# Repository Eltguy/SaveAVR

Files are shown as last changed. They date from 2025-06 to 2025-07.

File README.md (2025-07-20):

# SaveAVR

### HV-Programmiersystem für AVR-MCUs

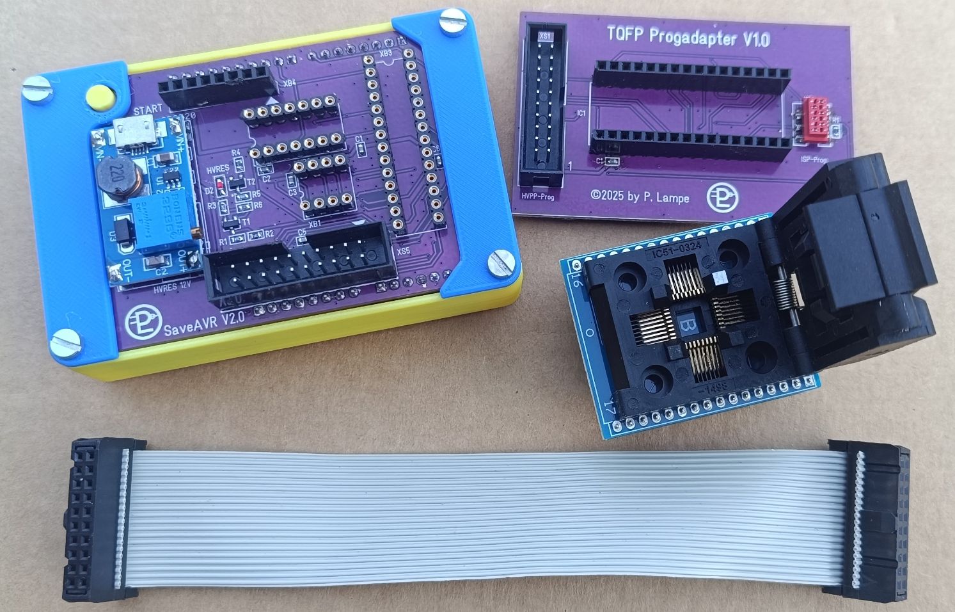
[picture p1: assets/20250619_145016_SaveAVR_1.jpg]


Ich hatte immer wieder Probleme mit AVR-Controllern, beim Setzen der Fuses. Insbesondere beim Entfernen des Vorteilers oder bei der Festlegung der Taktquelle, gab es mitunter Probleme beim Schreiben. Das Resultat war ein Controller, den man über den gängigen ISP-Modus nicht mehr programmieren kann. Laut Datenblatt gibt es dafür einen Ausweg - die Hochspannungsprogrammierung. Hochspannung bedeutet hier 12V. Legt man die an RESET an, ermöglicht das eine spezielle Programmierweise, unabhängig von der aktuellen Fuses- und Lockbitkonfiguration. Je nach Controllertyp kann das parallel (HVPP) oder seriell (HVSP) erfolgen.

Bei meinen Recherchen bin ich auf bereits vorhandene Lösungen gestoßen. Insbesonder die Variante, die im Artikel [RescueAVR](https://github.com/felias-fogg/RescueAVR) beschrieben wurde, fand ich sehr gut. Hier wird ein passendes HV-Programmer-Board beschrieben, das auf einen Arduino Uno aufgesetzt wird. Dieser enthält eine entsprechende Steuersoftware, mit der man über ein Terminalprogramm, die betroffenen MCUs wieder in deren Ursprungszustand zurückversetzen kann. Das Board funktioniert prima und ich möchte an dieser Stelle "felias-fogg" meinen Dank aussprechen.

### Systembeschreibung

Ausgehend von diesem Board, wurde eine eigene Variante für einen HV-Programmer entwickelt. Die Controller im DIL-Gehäuse werden von mir kaum genutzt. Mir war es deshalb wichtig, dass auch Controller mit TQFP32-Gehäuse unterstützt werden. Deshalb wurde von mir die 20pol. Buchsenleiste durch einen Wannenstecker ersetzt.  TQFP-Adapter gibt es preiswert über Aliexpress. Dafür habe ich einen separaten Programmieradapter designed. Dieser ist ebenfalls mit einem Wannenstecke ausgestattet. Die Verbindung erfolgt mit einem Flachbandkabel über Pfostenbuchsen. Zusätzlich hat der Adapter noch eine 6pol. Micromatch-SMD-Buchse. Darüber ist zusätzlich auch die ISP-Programmierung möglich. 

Des Weiteren habe ich als 12V-Quelle das allseits verfügbare Booster-Modul mit dem MT3608 verwendet. Letztendlich wurde das Routing noch optimiert und alles konsequent auf SMD-Bauelemente umgestellt.

Zur besseren Handhabbarkeit wurden alle Komponenten in ein Gehäuse aus 3D-Druckteilen eingebaut. Hierbei wurde auch an eine RESET-Knopf-Verlängerung für den Arduino Uno  gedacht, um das Terminalprogramm gegebenenfalls neu zu starten. Der Zusammenbau ist recht einfach und kann den Fotos und CAD-Ansichten entnommen werden. Unter der TQFP-Platine werden lediglich noch 4 selbstklebende Füße angebracht. 

Die Bauunterlagen des Projekts, inklusive die Gerber-Daten für die Leiterplatten, liegen im Ordner DOKUMENTE und sind auch auf meiner Webseite [Eltguy.de](https://eltguy.de/selbstbauprojekte-elektronik-technik-hobbytechnologien/flash-tools-programmiertool-esp-avr-adapter). Sie sind unter Beachtung der Lizenzbedingungen zur persönlichen Verwendung freigegeben. Bezüglich der Firmware für den Arduino Uno, verweise ich auf den Beitrag bei [RescueAVR](https://github.com/felias-fogg/RescueAVR). Ist die <em>RescuAVR.ino</em> einmal auf den Uno geflasht, kann man sich mit einem Terminalprogramm (z.B. Hterm), über den virtuellen COM-Port und einer Baudrate von 19200, mit dem Gerät verbinden. Dann ist einfach dem Programm zu folgen.

Bei Betrieb bitte beachten, dass die Controller <strong>nur bei abgeschalteter Betriebsspannung (USB-Stecker gezogen) gewechselt werden dürfen</strong> 👀️!

### Lizenzierung

Die hier beschriebenen Hardwarekomponenten dürfen ausschließlich für private Anwendungen gebaut und verwendet werden. Ich gestatte auch die Nutzung der bereitgestellten Entwicklungsunterlagen, die ich zum Download anbiete. Eine kommerzielle Nutzung schließe ich definitiv aus! Es ist nicht gestattet, Kennzeichnungen, die auf den geistigen Ursprung der Projekte hinweisen (Copyrights, Logos, Namen,…) aus Entwicklungsunterlagen der Anlage und Anlagenteilen zu entfernen. Nachbau und Nutzung erfolgen auf eigenes Risiko. Ich hafte nicht für Schäden, die durch die Nutzung der Software, der Anlage oder Anlagenkomponenten entstehen.

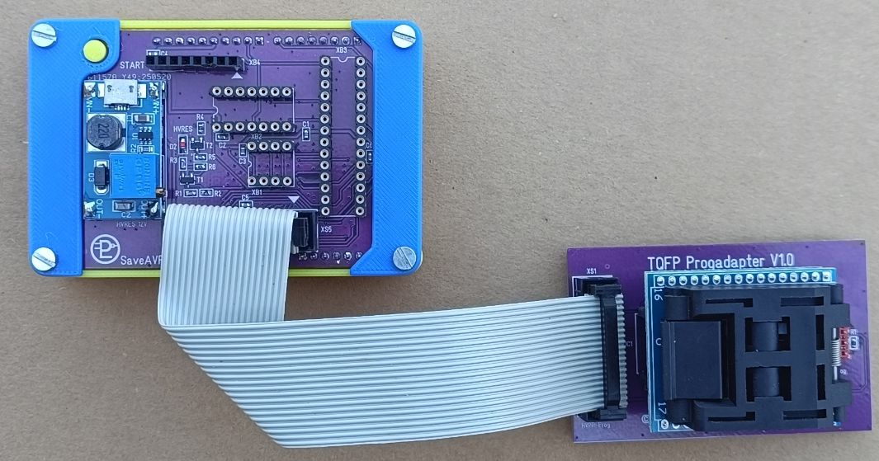
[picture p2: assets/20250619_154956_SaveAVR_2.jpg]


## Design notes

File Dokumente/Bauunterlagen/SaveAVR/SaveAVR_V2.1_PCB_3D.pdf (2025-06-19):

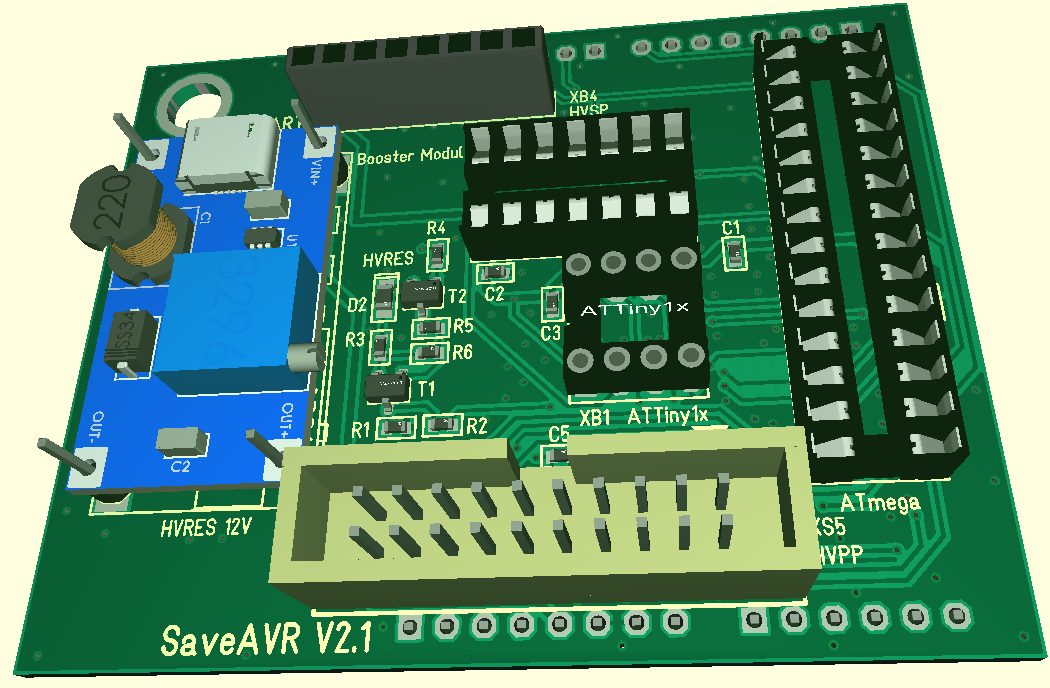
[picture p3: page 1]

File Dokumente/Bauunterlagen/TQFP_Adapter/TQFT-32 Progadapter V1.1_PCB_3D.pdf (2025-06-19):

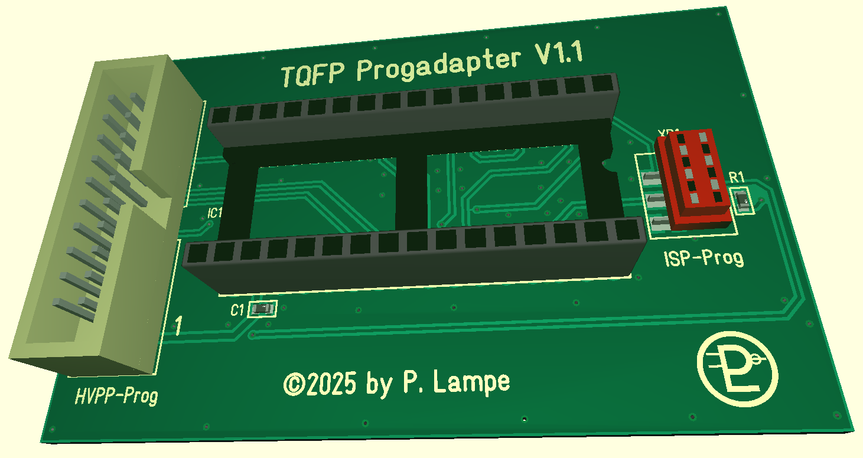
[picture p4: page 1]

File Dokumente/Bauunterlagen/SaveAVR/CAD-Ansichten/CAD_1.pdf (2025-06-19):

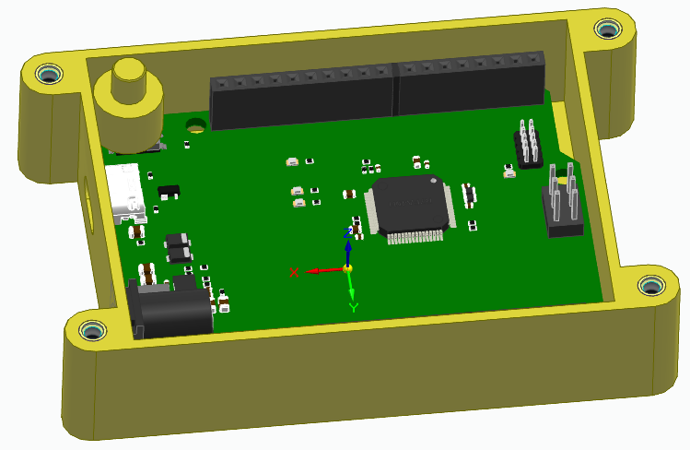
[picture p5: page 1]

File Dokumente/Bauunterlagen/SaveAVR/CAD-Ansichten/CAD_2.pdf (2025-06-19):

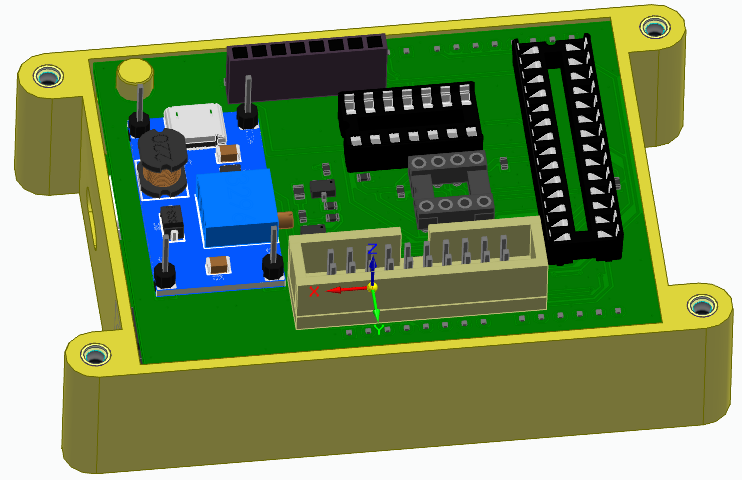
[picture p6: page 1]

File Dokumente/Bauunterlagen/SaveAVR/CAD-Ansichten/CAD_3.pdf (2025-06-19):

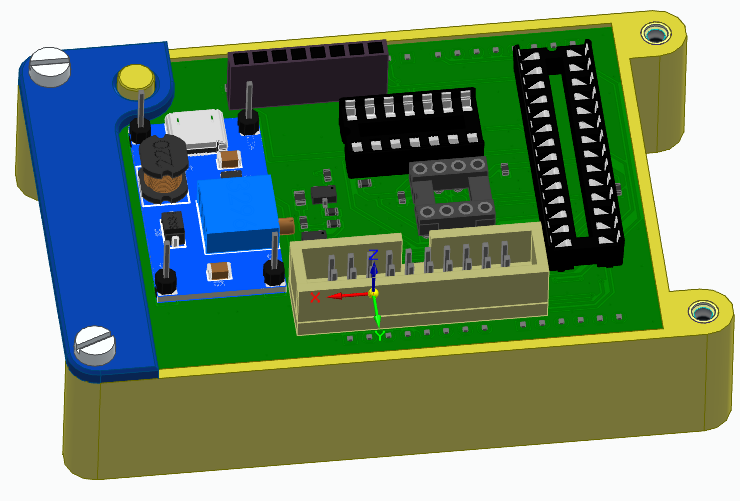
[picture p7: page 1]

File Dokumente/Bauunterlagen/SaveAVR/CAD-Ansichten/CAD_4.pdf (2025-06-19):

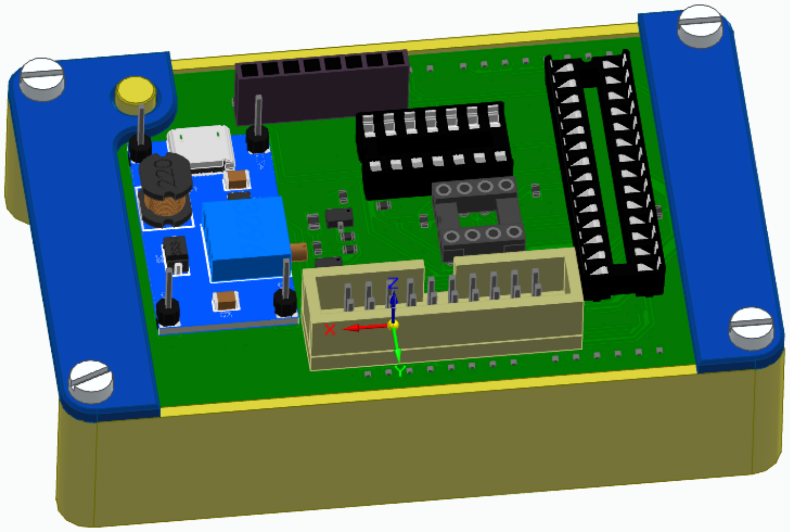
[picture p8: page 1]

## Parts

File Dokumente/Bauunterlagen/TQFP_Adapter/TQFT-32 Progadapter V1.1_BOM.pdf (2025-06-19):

## BOM

Datum 19.Juni.2025 12:32
Autor | Peter Lampe
Pos | Anzahl | Name | Wert | Gehäuse | Bemerkung
1 | 2 | C1, C2 | SMD-MLC 100n | 0603
2 | 2 | K2,K3 | 1X16_BUCHSE (TQFP-Socket) | 1X16_BUCHSE
3 | 1 | R1 | SMD-Widerstand 82k | 0603
4 | 1 | XB1 | Micromatch-SMD-Buchse 6pol. (ISP-Prog) | Micromatch 6pol
5 | 1 | XS1 | Wannenstecker 2x10pol (HVPP) | WANNENSTECKER-20-ST
6 | 4 | | selbstklebende Füße, unter PCB kleben | | Aliexpress (https://de.aliexpress.com/item/1005004068119765.html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)
7 | 1 | TQFP32-Adapter, in Pos.2 stecken

Aliexpress (https://de.aliexpress.com/item/1005007044669572.html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)

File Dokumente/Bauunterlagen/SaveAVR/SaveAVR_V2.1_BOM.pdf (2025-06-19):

### BOM

Datum | 19.Juni.2025 11:30
;Autor | Peter Lampe
Pos | Anzahl | Name | Wert | Gehäuse | Bemerkung
1 | 6 | C1...C6 | SMD-MLC 100nF | 0603
2 | 1 | R2 | SMD-Widerstand 100 | 0603
3 | 3 | R1, R3, R5 | SMD-Widerstand 1k | 0603
4 | 1 | R4 | SMD-Widerstand 4,7k | 0603
5 | 1 | R6 | SMD-Widerstand 10k | 0603
6 | | D2 | rt | 0805
7 | 1 | T1 | SMD-Transistor; pnp; BC857A | SOT23/3
8 | 1 | T2 | SMD-Transistor;npn; BC846A | SOT23/3
9 | 4 | KL1...KL4 | Stiftleiste 1x1pol | Stiftleiste_1x01_G_2,54
10 | 1 | M1 | Booster Modul MT3608 | MT3608_PCB | Aliexpress (https://de.aliexpress.com/item/1005007329944366.html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)
11 | 1 | XB1 | IC-Fassung 2x4 (ATTiny1x) | IC-SOCKET_DIL8 MACHINE PIN
12 | 1 | XB2 | IC-Fassung 2x8 (ATtinyX4) | IC-FASSUNG RM 7.62 - 14 POLIG
13 | 1 | XB3 | IC-Fassung 2x14 (ATmegax8) | IC-FASSUNG RM 7.62 - 28 POLIG
14 | 1 | XB4 | Buchsenleiste 1x8pol. (HVSP) | 1X08_BUCHSE
15 | 2 | XS1, XS3 | Stiftleiste 1x8pol | Stiftleiste_1x08_G_2,54
16 | 1 | XS2 | Stiftleiste 1x10pol | Stiftleiste_1x10_G_2,54
17 | 1 | XS4 | Stiftleiste 1x6pol | Stiftleiste_1x06_G_2,54
18 | 1 | XS5 | Wannenstecker 2x10pol (HVPP) | WANNENSTECKER-20-ST

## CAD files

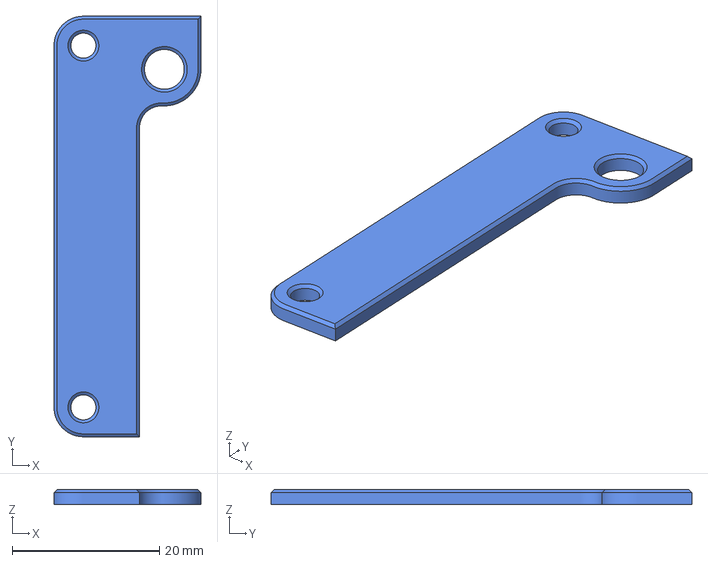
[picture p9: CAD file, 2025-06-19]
Dokumente/3D-Teile/Abdeckklammer Knopf.3mf
20.0 x 57.2 x 2.00 mm

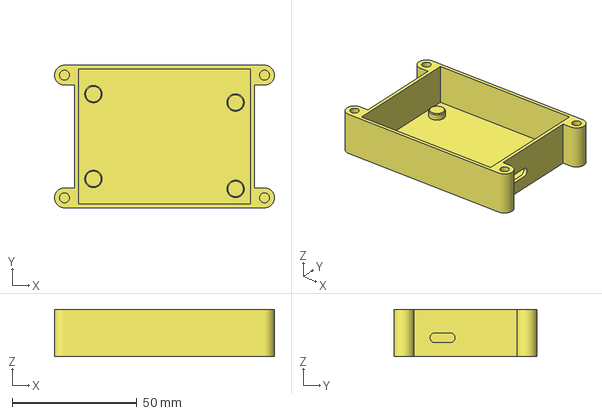
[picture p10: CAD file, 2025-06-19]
Dokumente/3D-Teile/saveAVR_Unterschale.3mf
88.2 x 57.2 x 19.0 mm

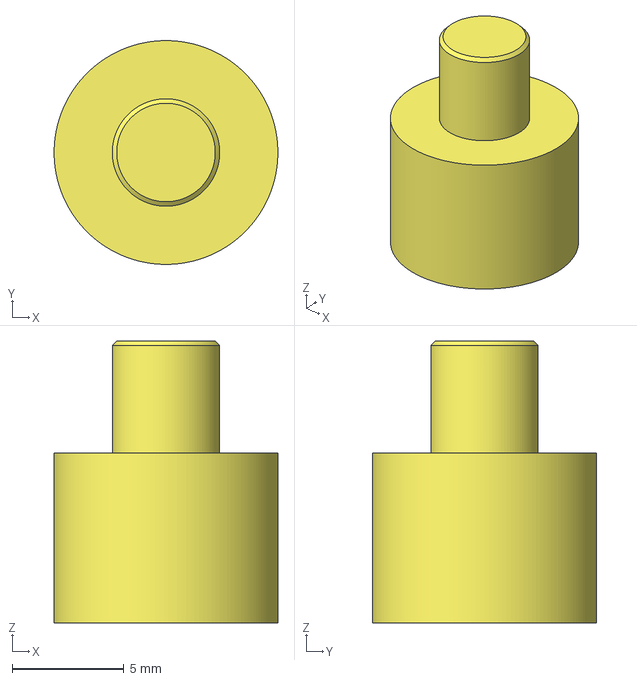
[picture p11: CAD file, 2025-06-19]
Dokumente/3D-Teile/Druckknopf 2.3mf
10.0 x 10.00 x 12.6 mm

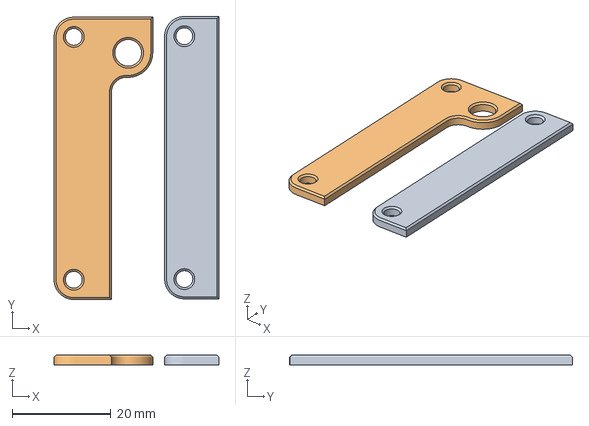
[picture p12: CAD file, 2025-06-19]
Dokumente/3D-Teile/Abdeckklammer.3mf
33.4 x 57.3 x 2.00 mm
Abdeckramen einfach
Abdeckramen Knopf

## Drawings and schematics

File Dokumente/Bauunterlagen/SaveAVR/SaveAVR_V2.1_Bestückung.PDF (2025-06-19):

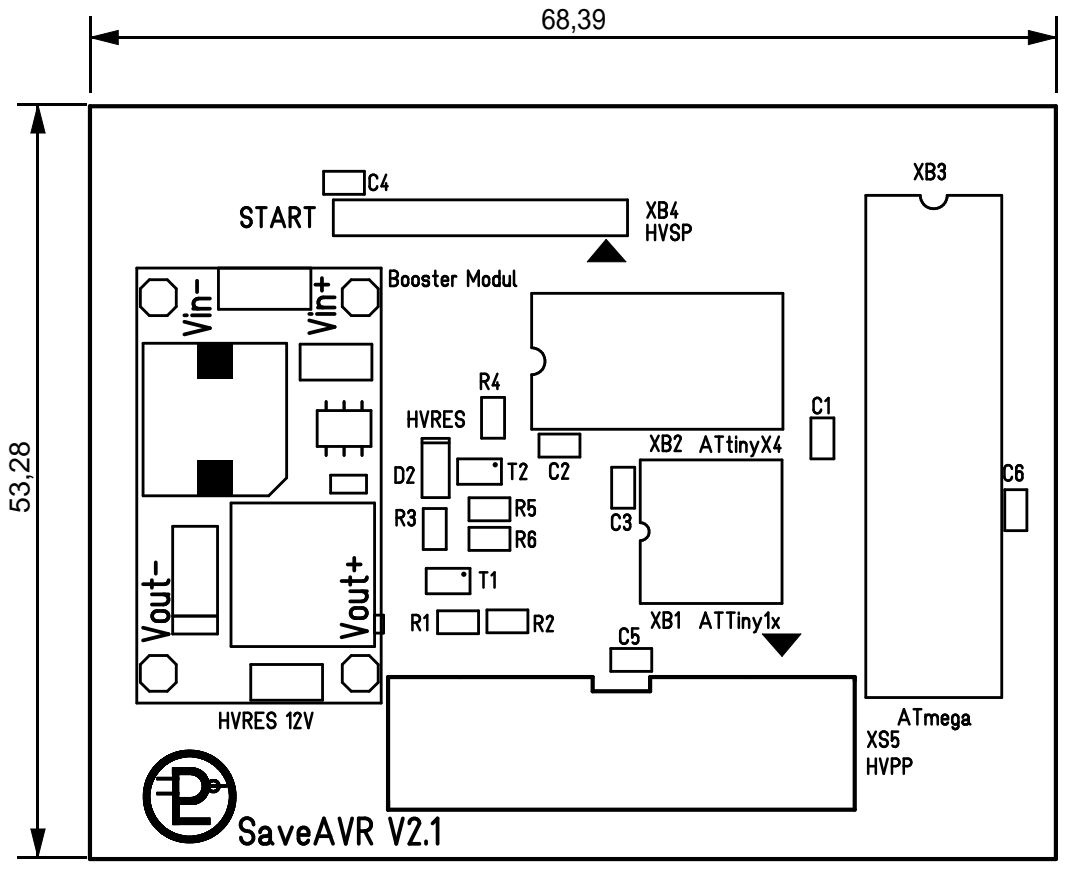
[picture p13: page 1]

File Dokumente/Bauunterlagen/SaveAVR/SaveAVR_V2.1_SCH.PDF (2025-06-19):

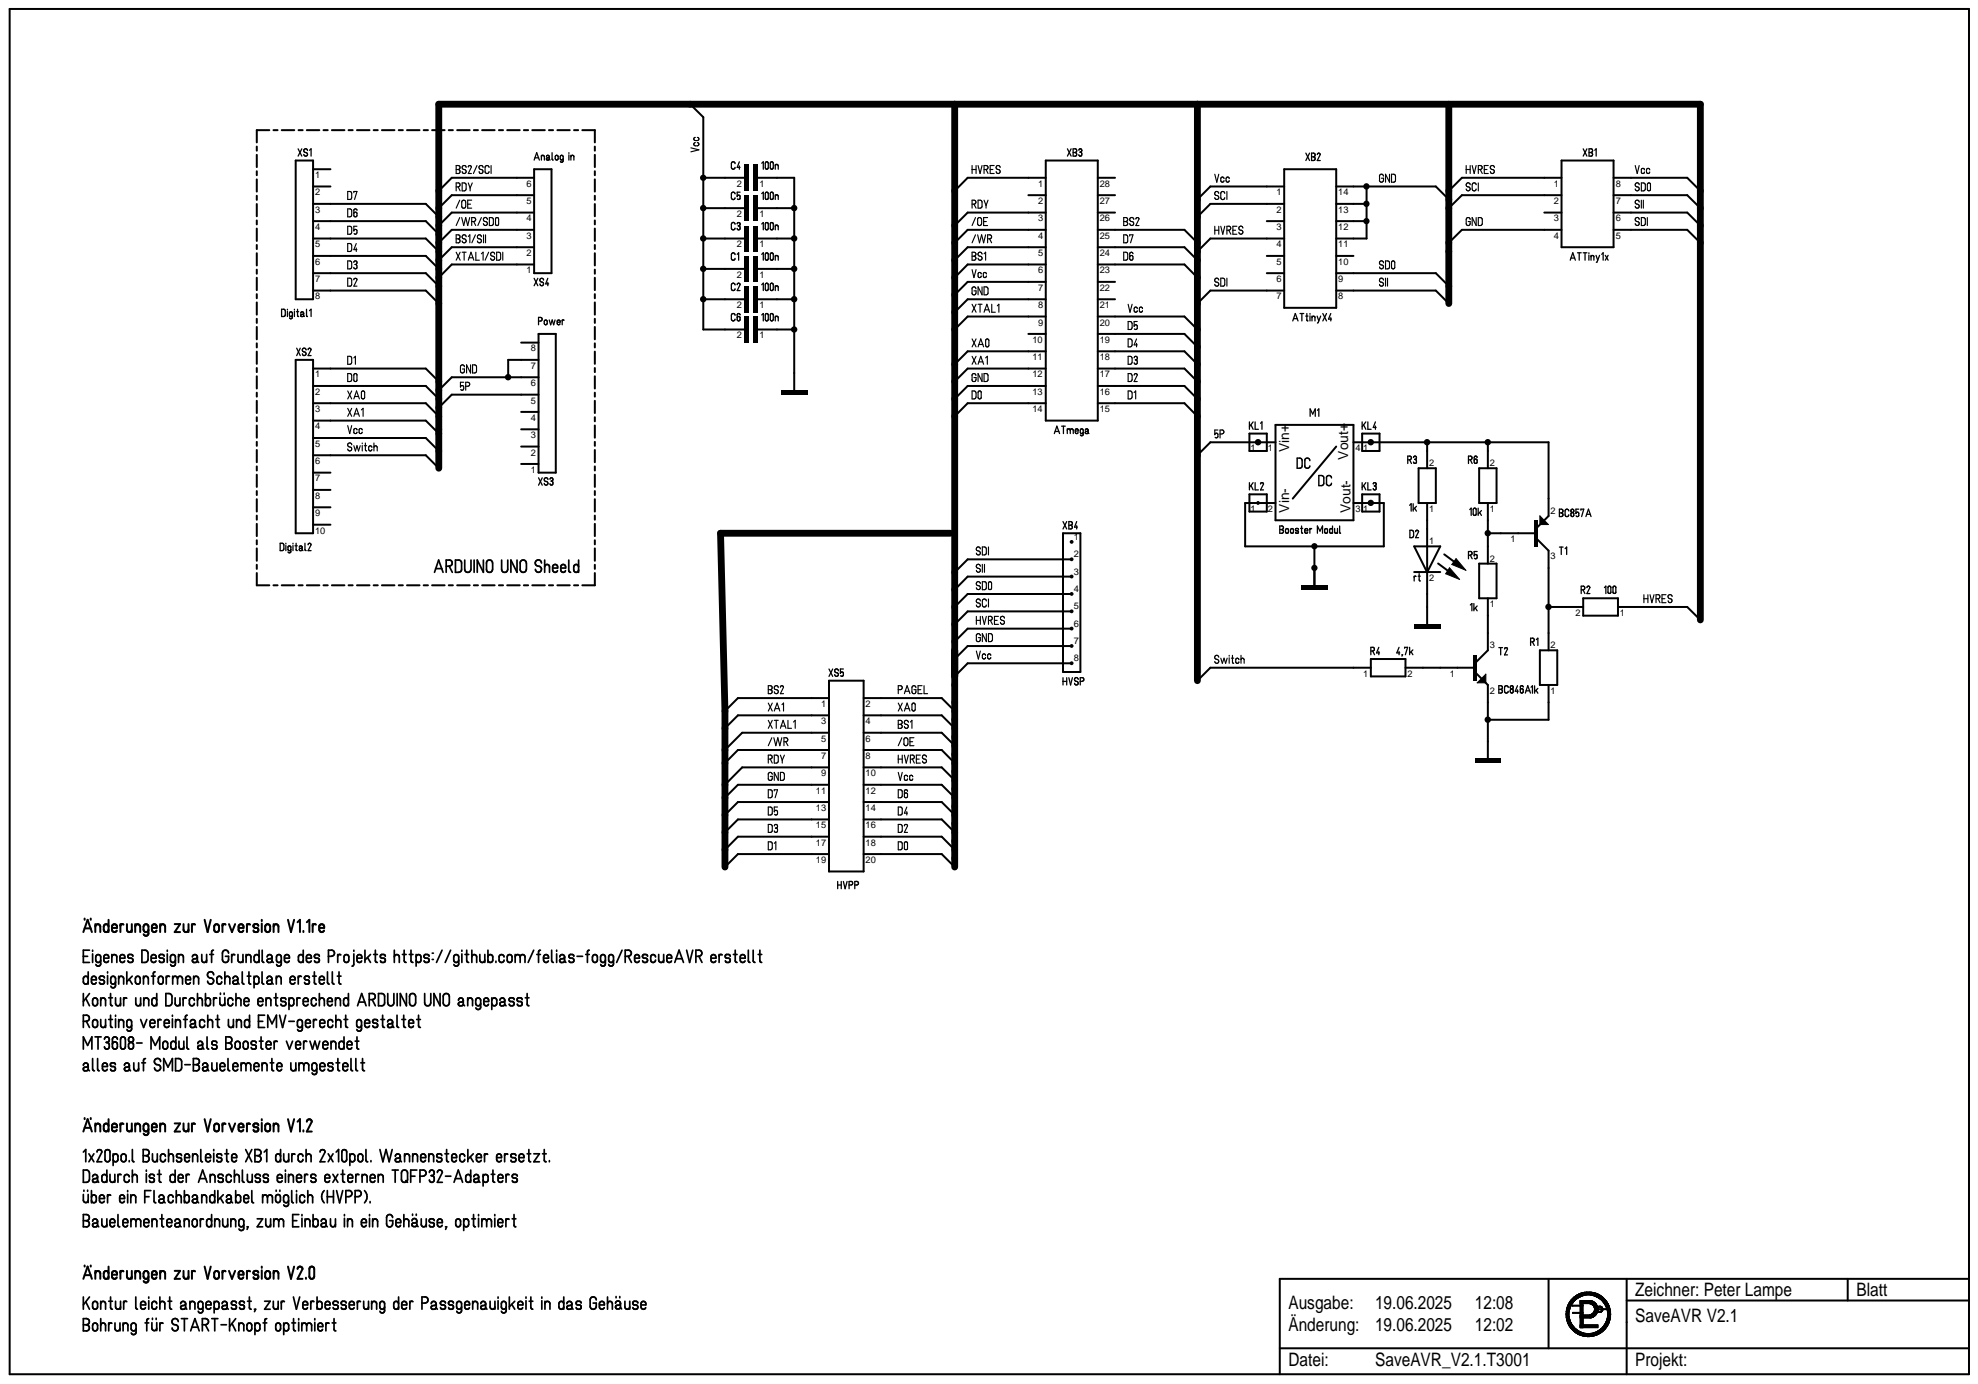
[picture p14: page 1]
Vin+; Vin-; Vout-; 34 Vout+; SaveAVR_V2.1.T3001; Ausgabe: Änderung:; Projekt:; SaveAVR V2.1; Zeichner: Peter Lampe; Blatt; Datei:

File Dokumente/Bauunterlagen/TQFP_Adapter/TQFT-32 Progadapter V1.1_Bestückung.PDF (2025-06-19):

73

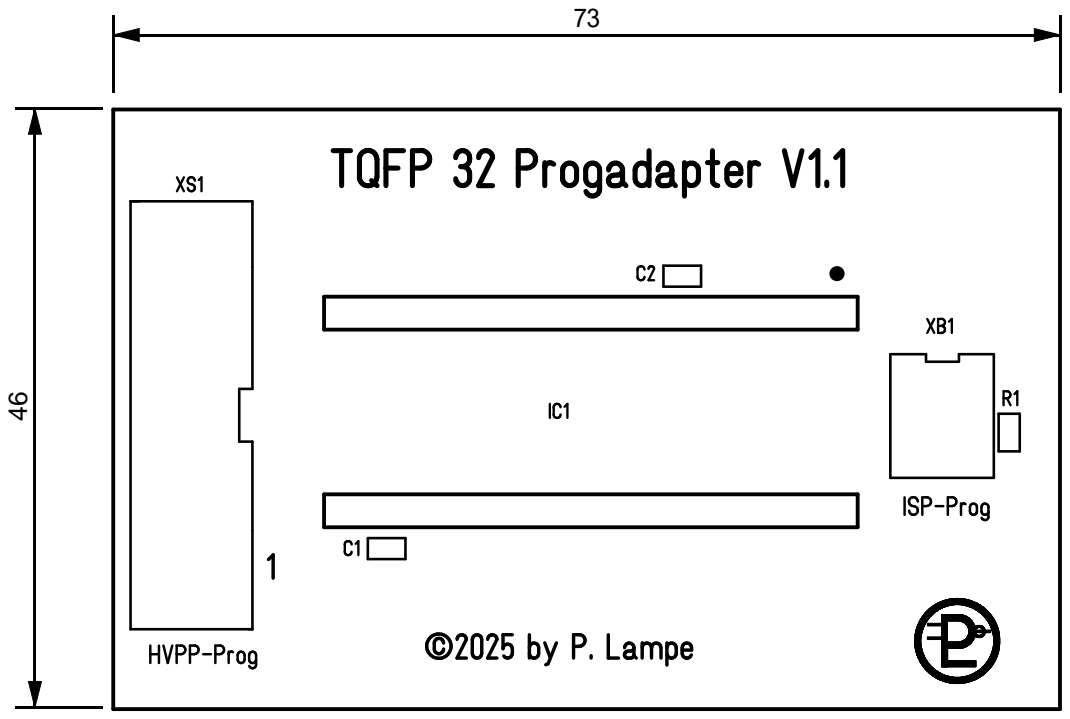
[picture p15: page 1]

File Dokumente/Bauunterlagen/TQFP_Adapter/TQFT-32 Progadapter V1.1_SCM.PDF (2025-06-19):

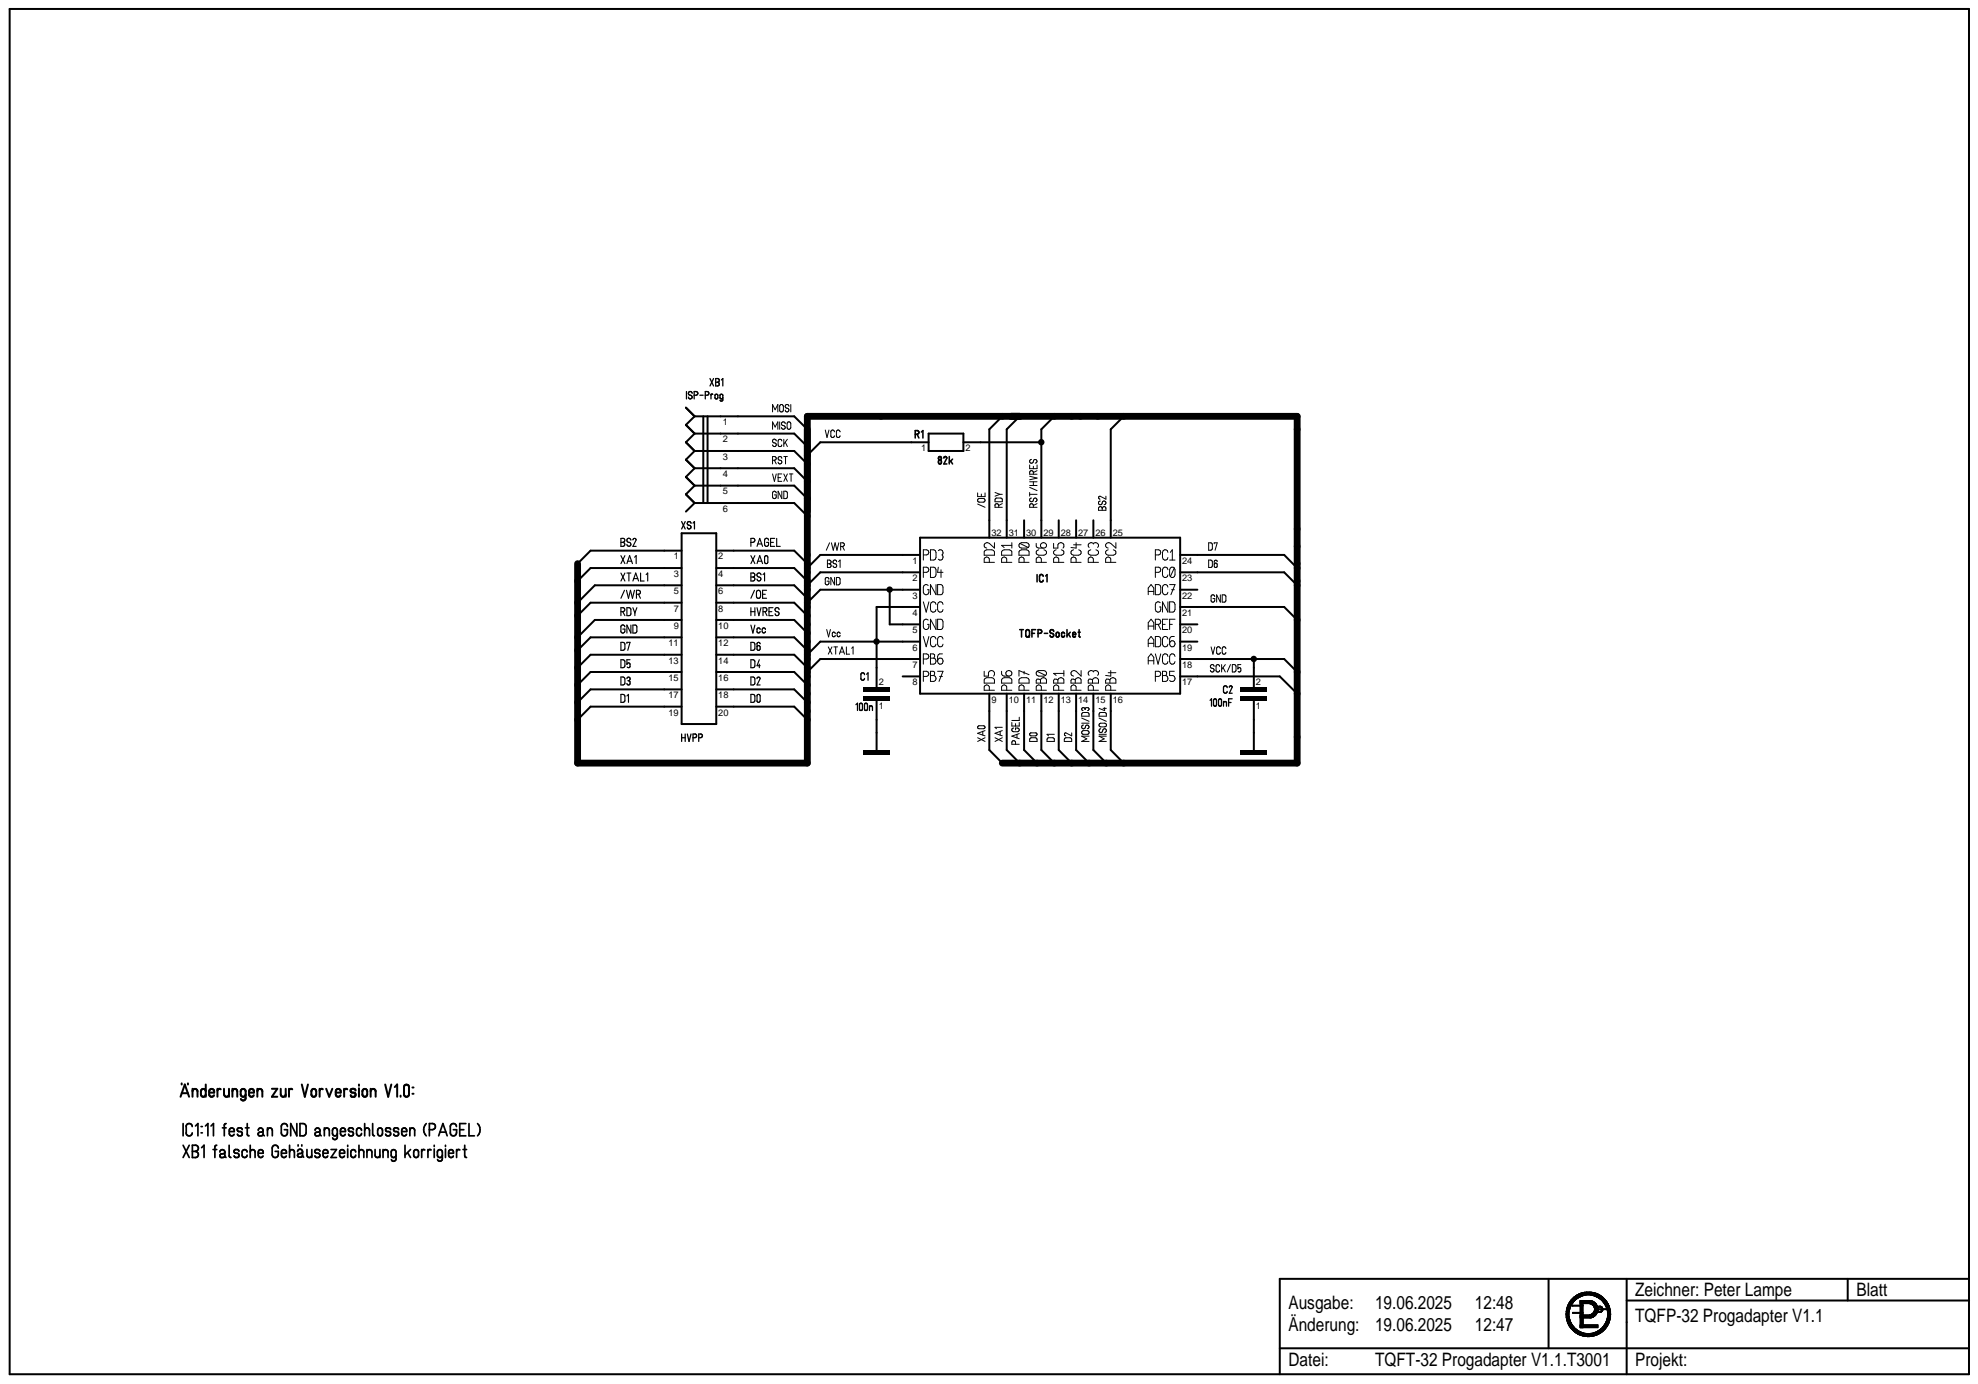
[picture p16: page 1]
TQFT-32 Progadapter V1.1.T3001; Ausgabe: Änderung:; Projekt:; TQFP-32 Progadapter V1.1; Zeichner: Peter Lampe; Blatt; Datei:
